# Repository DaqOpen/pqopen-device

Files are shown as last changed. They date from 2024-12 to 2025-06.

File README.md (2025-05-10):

# pqopen-device

**pqopen-device** is a cost-effective, open-source measurement device for monitoring voltage and current within electrical distribution panels. It includes power quality (PQ) functionalities compliant with **IEC 61000-4-30** and is designed for tech enthusiasts and educational institutions. It bases on the [daqopen-lib](https://github.com/DaqOpen/daqopen-lib) for  data acquisition and [pqopen-lib](https://github.com/DaqOpen/pqopen-lib) for the power quality processing part.

> [!WARNING] 
> The actual hardware design is not tested so far. Please wait until an official release.

## Key Features

- **Voltage Measurement**: Measure and analyze 3-phase mains voltage up to 330 VAC
- **Current Measurement**: Use clamps like SCT13-0000 for current measurement
- **Power Quality**: Analysis of RMS, Harmonics, Interharmonics, Flicker and more according to IEC 61000-4-30
- **Data Aggregation**: Use different storage intervals for logging selected parameters to CSV or MQTT
- **Cost-Effective**: Built using open-source hardware like the **Arduino Due** and **Raspberry Pi**.

## Target Audience

- **Tech Enthusiasts**: People interested in measurement technology and electrical energy supply.
- **Educational Institutions**: For training and research purposes.

## Hardware Overview

The device comprises:

- A custom **mainboard** with connectors, power supplies, and signal conditioning for voltage and current.
- **Arduino Due** for data acquisition (running with 55 kS/s per channel)
- **Raspberry Pi 3A+** as the edge device.
- A **standard DIN-rail enclosure** (9 module width).

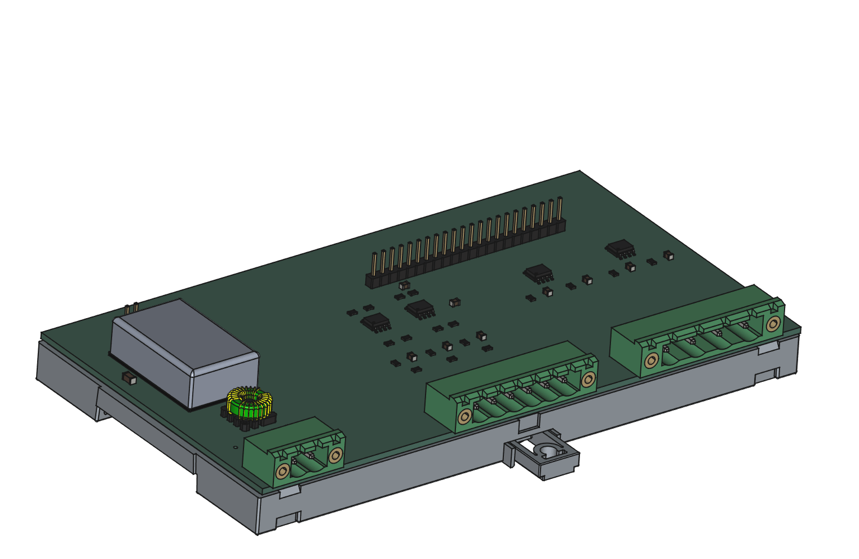
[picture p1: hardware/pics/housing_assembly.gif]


The main pcb is dual layer with components on both sides. It uses typically SMT components with down to size of 0805 to be soldered by hand.

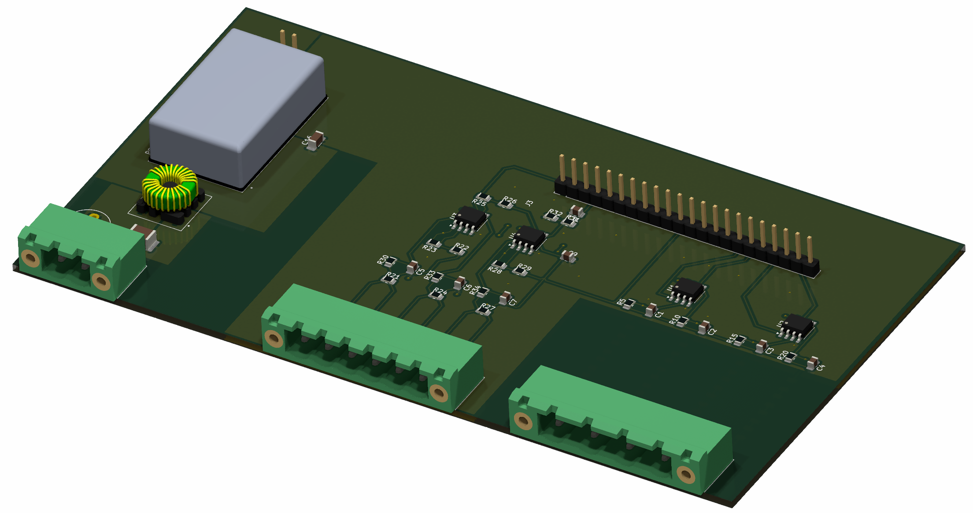
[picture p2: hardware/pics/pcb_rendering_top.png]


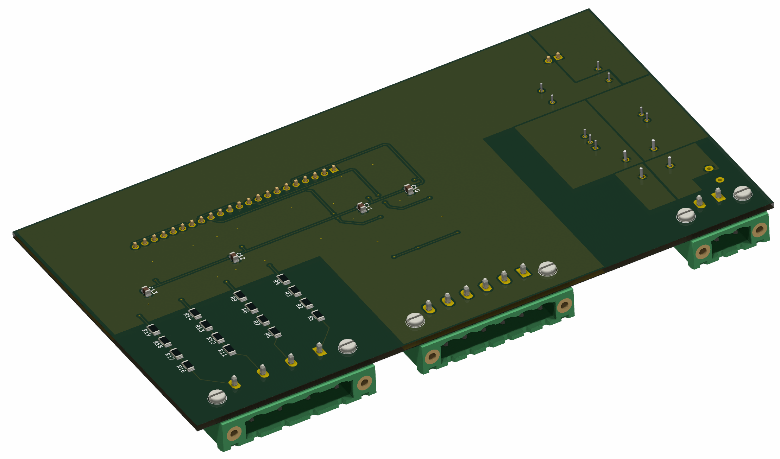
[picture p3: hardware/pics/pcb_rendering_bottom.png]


## Software Overview

The software is split into several components:

### Firmware for Arduino Due

Runs on the Arduino Due for ADC data acquisition (see https://github.com/DaqOpen/daqopen-lib)

Written in C++ for Arduino IDE

### Software for Raspberry Pi

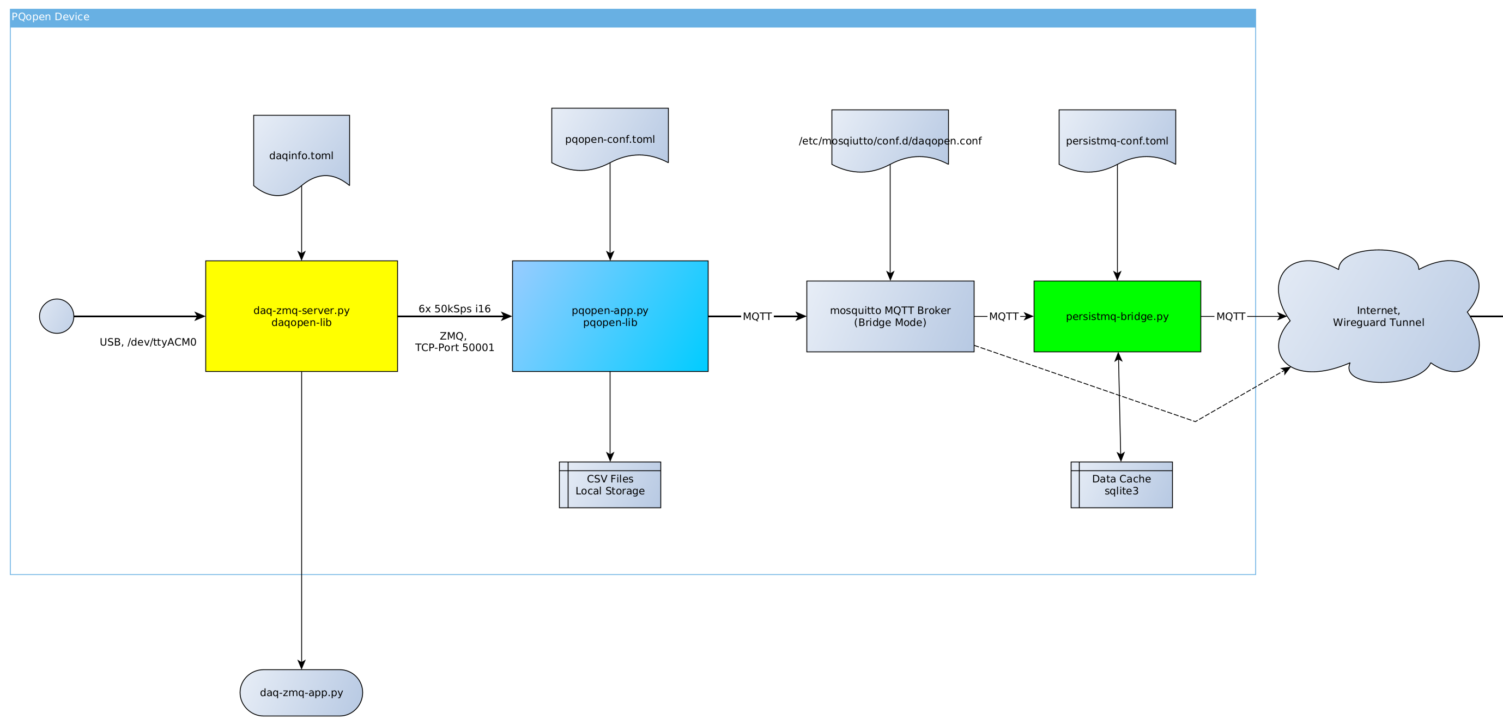
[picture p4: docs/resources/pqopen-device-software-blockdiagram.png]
PQopen Device Software


There are three main software components running on the Raspberry Pi edge device to fulfill the measurement needs:

#### daqopen-zmq-server.py

This is the data entry point for the further processing. It receives data form the Arduino Due, adds timestamps as well as channel properties and provides the data via a ZMQ PUB/SUB interface.

This service is time critical due to limited buffer on the Arduino Due and is therefore started with higher priority and realtime scheduler option.

#### pqopen.py

The pqopen app is the main processing application. It connects to the daqopen-zmq-server and receives the data, calculates power values and outputs it on the configured interfaces.

#### persistmq-bridge.py

When data loss is no option, the persistmq-bridge helps to cache data in case of connection loss and resending capability.

## Platform Compatibility

- **Core Library**: Runs on ARM64, AMD64, Linux, and Windows (Mac compatibility untested).
- **Main Application**: Designed specifically for the Raspberry Pi.

## Installation

An **initial setup guide** will be provided to assist with assembling the hardware and installing the software soon.

## Documentation

Documentation for the overarching project is available at [docs.daqopen.com](https://docs.daqopen.com). This documentation will be expanded to include specifics for pqopen-device.

## Contribution

Contributions are welcome, provided they align with the project's vision. Feel free to open issues, submit pull requests, or engage in discussions.

## License

This project is licensed under the **MIT License**.

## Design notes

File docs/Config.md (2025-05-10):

# Configuration

There are three main configuration files placed in /etc/pqopen/ directory.

| File | Configuration for |
| --- | --- |
| daqinfo.toml | daqopen-zmq-server<br />Information about the ACQ system, inputs and zmq server |
| pqopen-conf.toml | pqopen<br />Power system information and phases. Storing Endpoints |
| persistmq.conf | persistmq-bridge<br />Source and target of the MQTT messages; Cache-file |

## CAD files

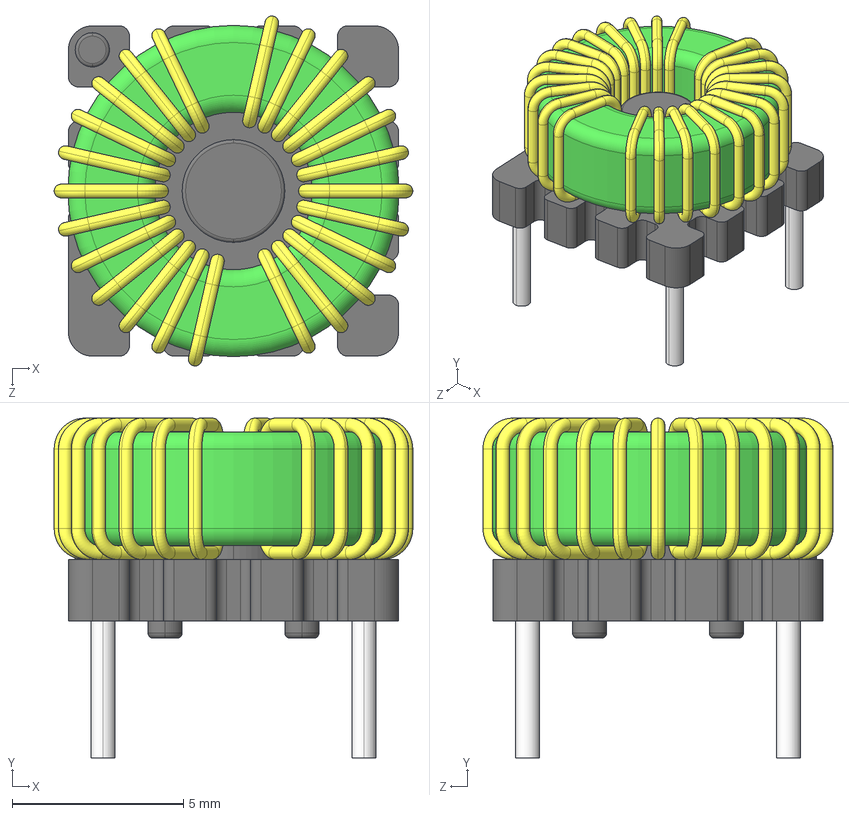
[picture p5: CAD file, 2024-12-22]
hardware/schematic-rail-mount/footprints/tck_050_3d_drawing.stp
10.5 x 9.93 x 10.2 mm

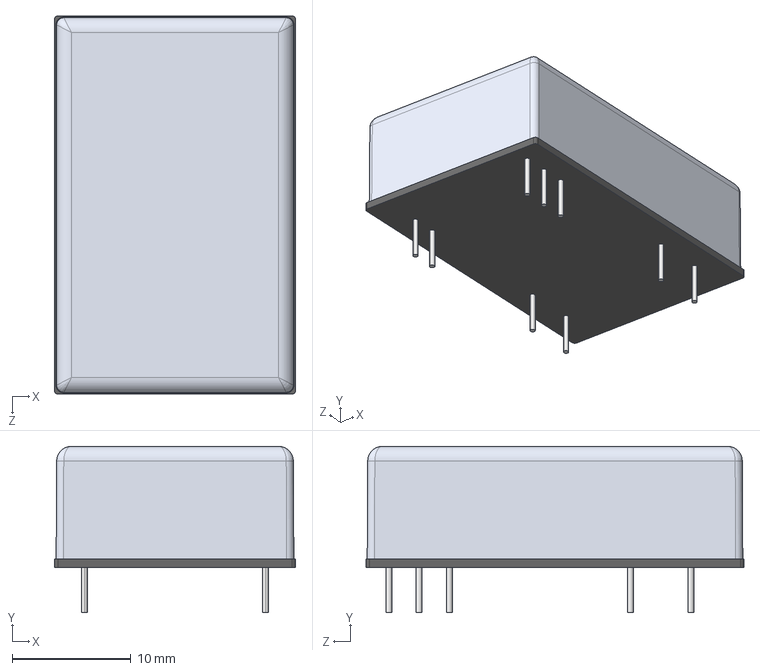
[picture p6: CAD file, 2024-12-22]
hardware/schematic-rail-mount/footprints/ten8wi_3d_drawing.stp
20.3 x 14.0 x 31.8 mm

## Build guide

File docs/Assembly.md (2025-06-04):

# Assembly of PQopen (Din-Rail)

This Section describes the assembly of the PQopen device. 

Components

| Item | Count | Info |
| --- | ----- | --- |
| pqopen-base-board | 1 | PQopen Base Board with pre-soldered top SMT parts |
| Arduino Due | 1 | Arduino Due is used as DAQ Board. Flashed with DueDaq Firmware<br />See [Arduino Setup](../../how-to/prepare-arduino-due.md) |
| Raspberry Pi 3A+  | 1 | Edge Computer + SD-Card (min. 8 GB) |
| 9TE Housing | 1 | e.g. Camdenboss CNMB/9/KIT |

Additional Parts for PCB Completion

| Item | Count | Info |
| --- | ----- | --- |
| TEN 8-2411WI | 1 | DC/DC Converter |
| TCK-050 | 1 | Filter Choke |
| C1812F475K5RACTU | 1 | DC Input Capacitor |
| Phoenix 1806245 | 1 | 4 Pos 7.62mm pitch Through Hole Header  |
| Phoenix 1858785 | 1 | 4 Pos 7.62mm pitch Plug 24-12 AWG Screw |
| Phoenix 1776540 | 1 | 6 Pos 5.08mm pitch Through Hole Header  |
| Phoenix 1778027 | 1 | 6 Pos 5.08mm pitch Plug 24-12 AWG Screw |
| Phoenix 1776508 | 1 | 2 Pos 5.08mm pitch Through Hole Header  |
| Phoenix 1777989 | 1 | 2 Pos 5.08mm pitch Plug 24-12 AWG Screw |
| ROHM KTR18EZPF4703 | 16 | 470 kOhm Resistors for input divider |

## Step 1: Completion of PCB

This chapter shows the completion of the PCB of Revision 1.

### Power Supply

At first, we start with the power supply part. For this step, we need the following parts:

| | Count | Info |
| --- | ----- | --- |
| TEN 8-2411WI | 1 | DC/DC Converter |
| TCK-050 | 1 | Filter Choke |
| C1812F475K5RACTU | 1 | DC Input Capacitor |
| T2A | 1 | Input fuse 2A |

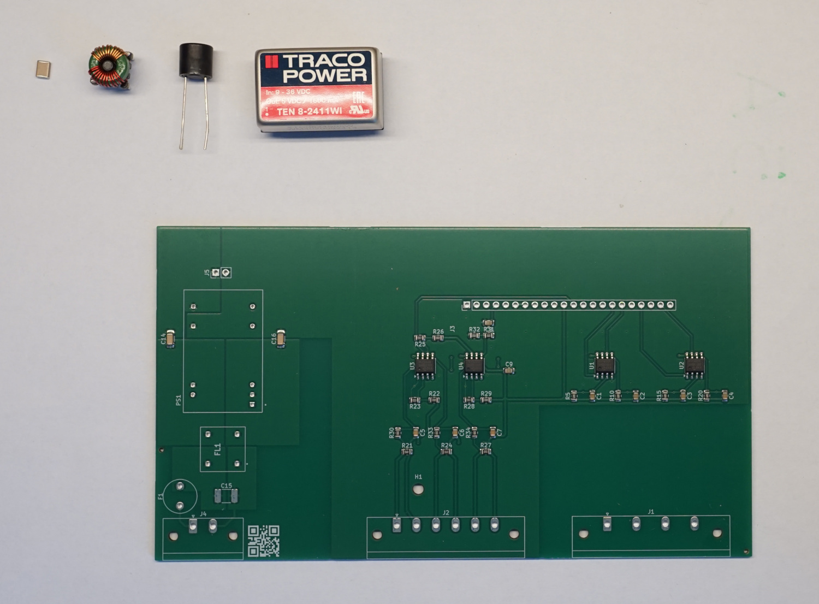
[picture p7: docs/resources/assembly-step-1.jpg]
Step1


Start with the smallest part, the capacitor.

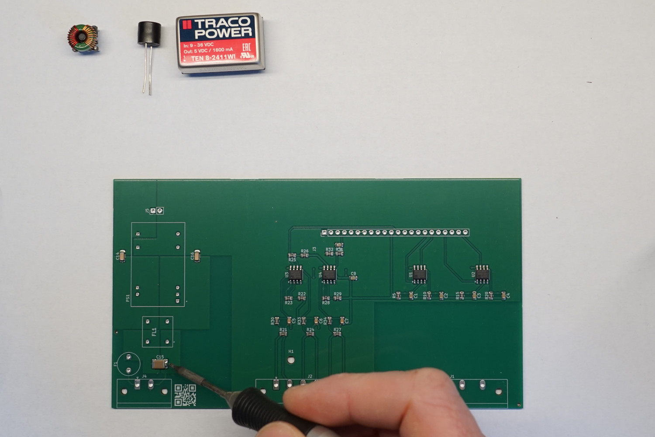
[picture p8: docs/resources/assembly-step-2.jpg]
Step1-A


And work towards the DC/DC converter:

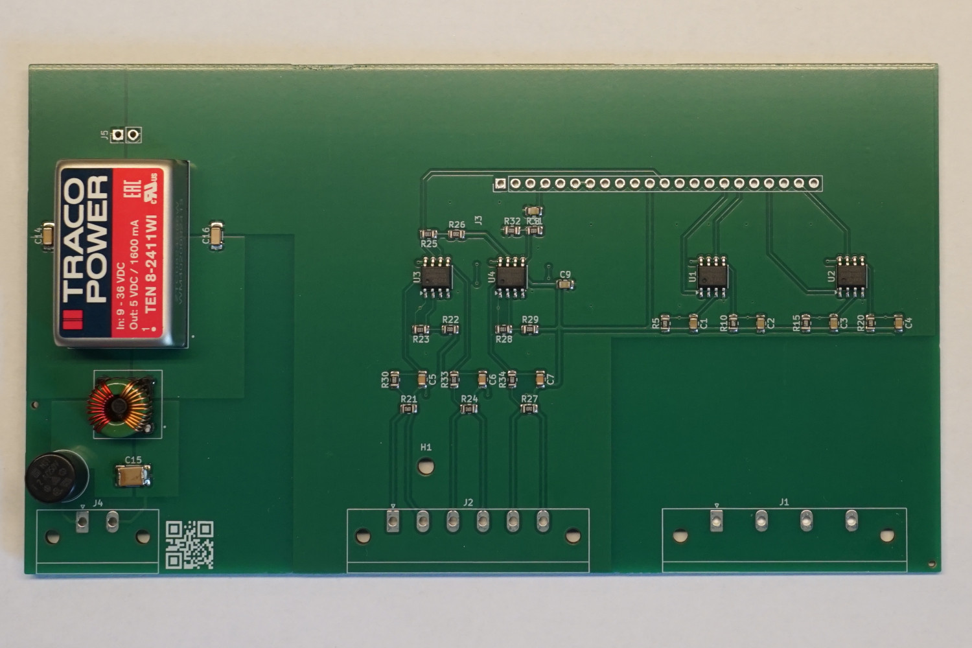
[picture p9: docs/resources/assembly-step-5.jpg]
Step1-B


### Backside Capacitors

C10-C13: 100nF 0805

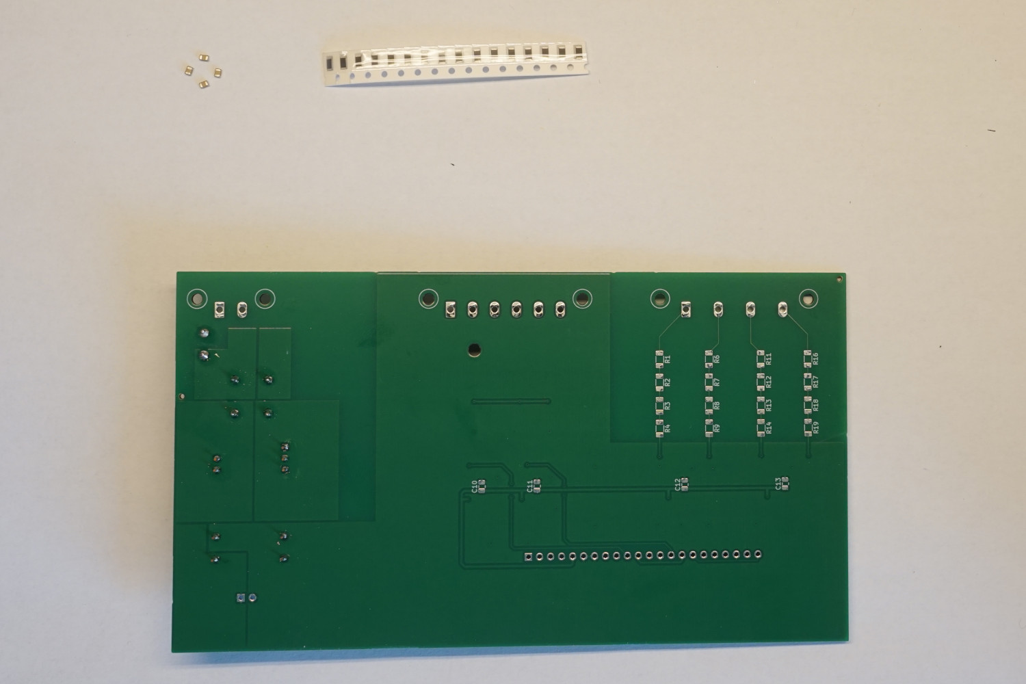
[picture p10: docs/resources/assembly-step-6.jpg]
Step3-A


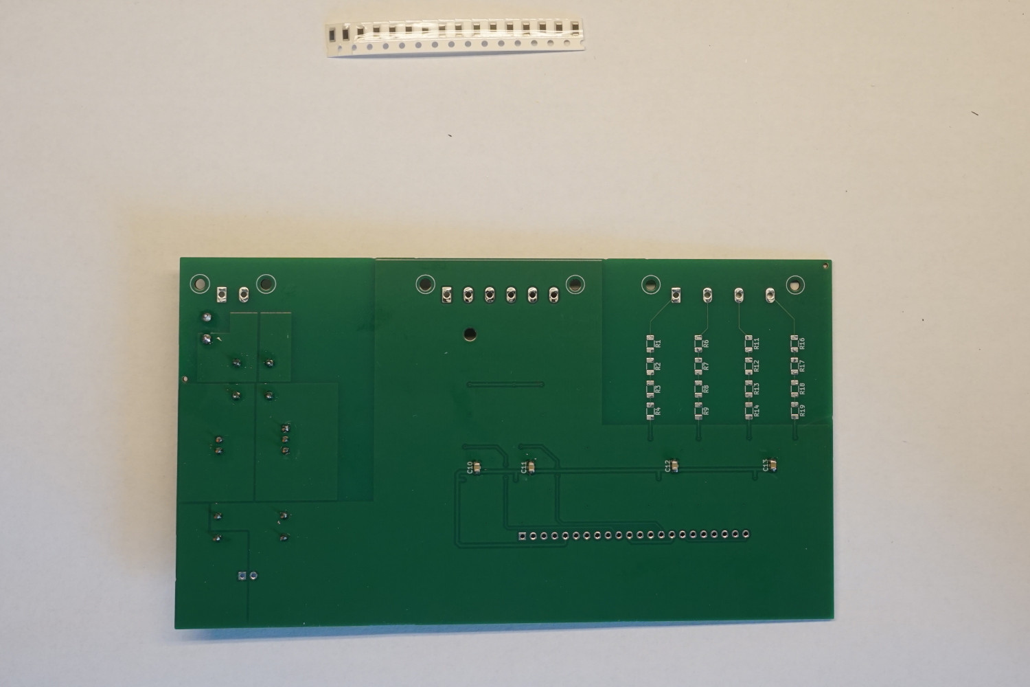
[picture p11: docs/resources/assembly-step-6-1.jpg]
Step3-B


### Input voltage divider

The resistive voltage divider is used to reduce the power grid voltage to ADC levels. It consists of each 4 resistors. 

#### Resistor selection (optional)

To improve accuracy across all 3 input channels, the resistors should be equal value. One option to select the right combination of resistors of each string, is, to sort the resistors according to actual measured value. My way of doing this is, checking each resistor and placing it on a scale, which I draw on paper.

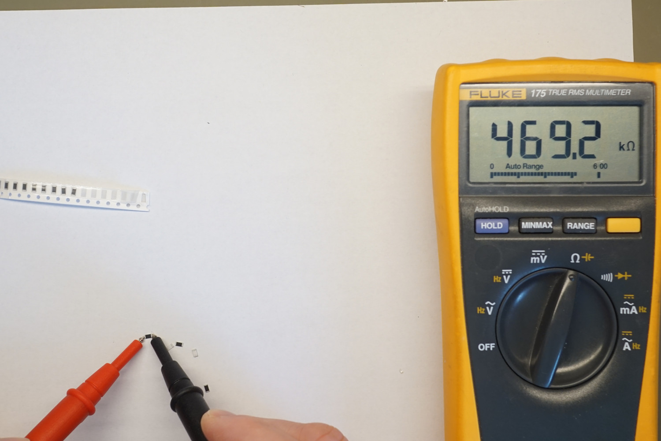
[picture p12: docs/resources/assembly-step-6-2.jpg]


After sorting all resistors, the placement should look something like this:

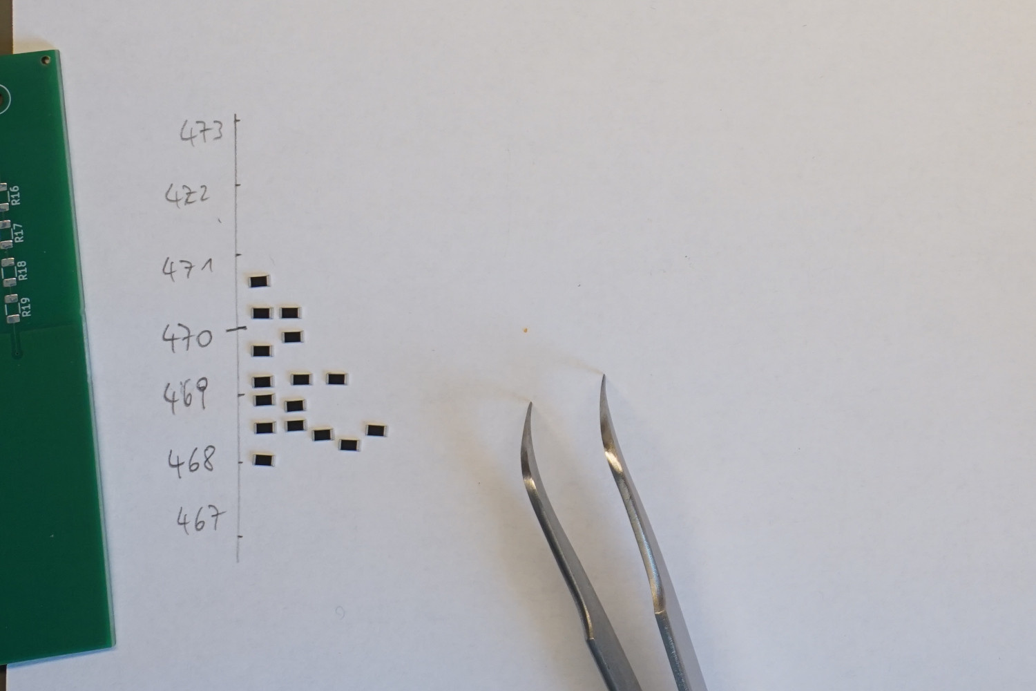
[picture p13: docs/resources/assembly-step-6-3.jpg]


Now use the resistors alternating top and bottom. This should give you a good mix of values to reach almost same series value.

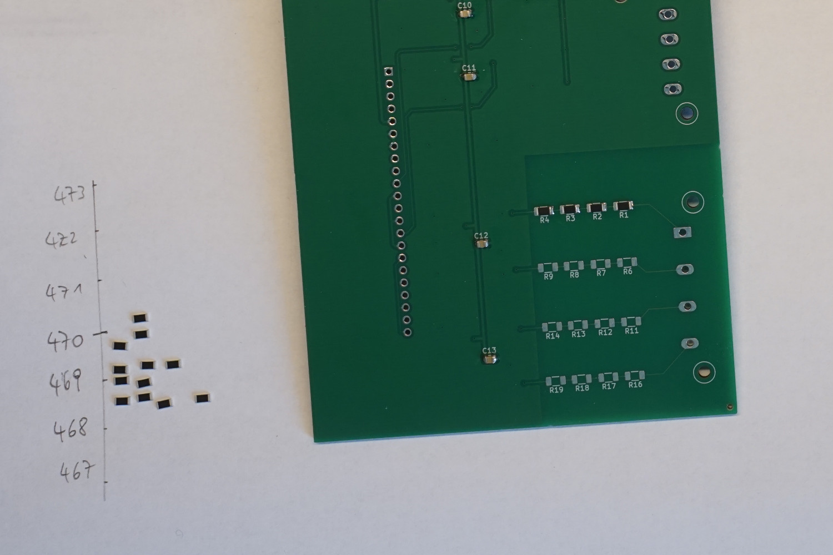
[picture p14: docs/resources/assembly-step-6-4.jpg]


Here I used the two most top and tow of most bottom resistors and placed them on the first string.

#### Finishing voltage divider

Place all 16 resistors to finish the voltage input divider.

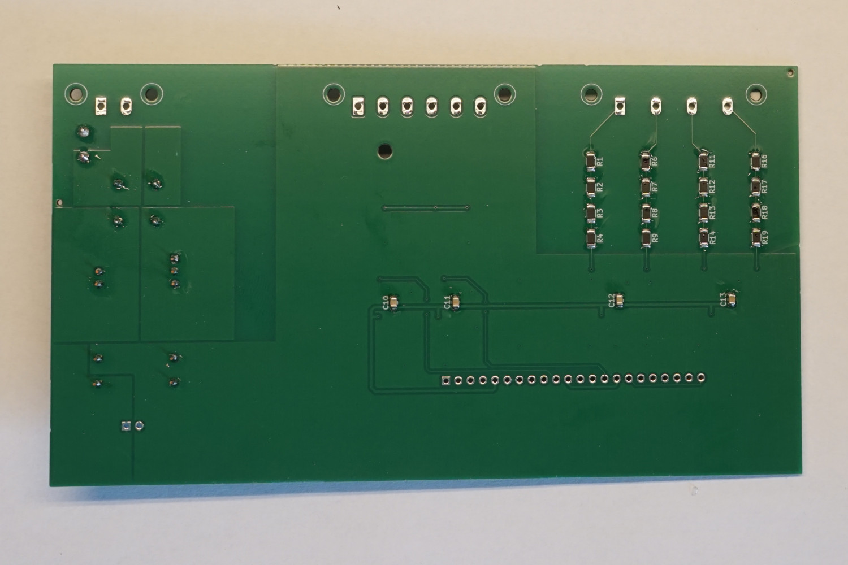
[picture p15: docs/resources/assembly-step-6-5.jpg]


### Pinheader for Arduino

Next, we'll place the pinheader for the Arduino Due. You need a standard 2.54 RM Pinheader with 22 pins. Remove the pins from position 9 and 18 to fit with the Arduino socket.

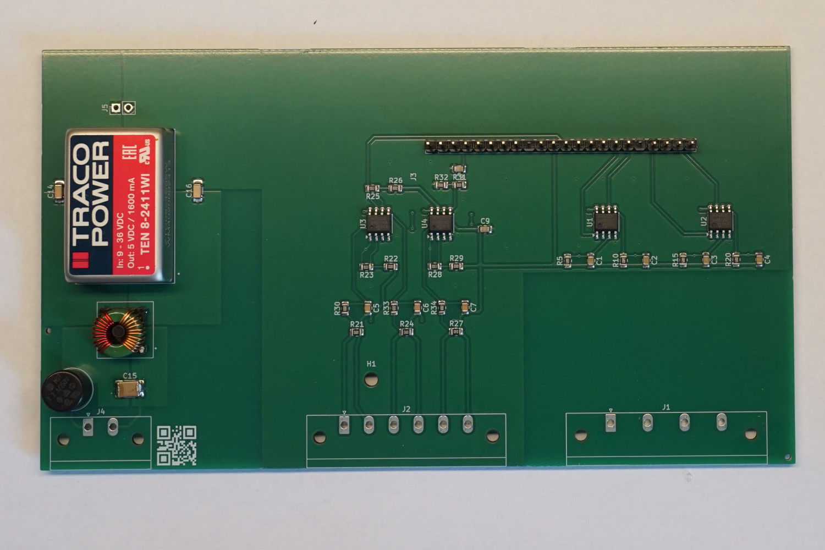
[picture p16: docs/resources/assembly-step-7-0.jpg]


### Input connectors

To finish the PCB assembly, solder the input connectors for power supply, current sensor and voltage input.

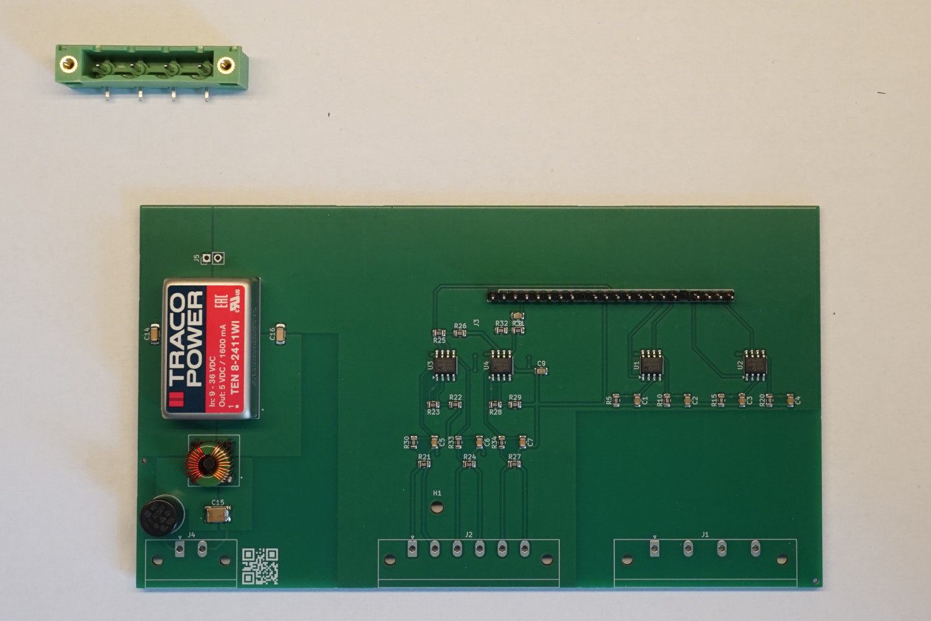
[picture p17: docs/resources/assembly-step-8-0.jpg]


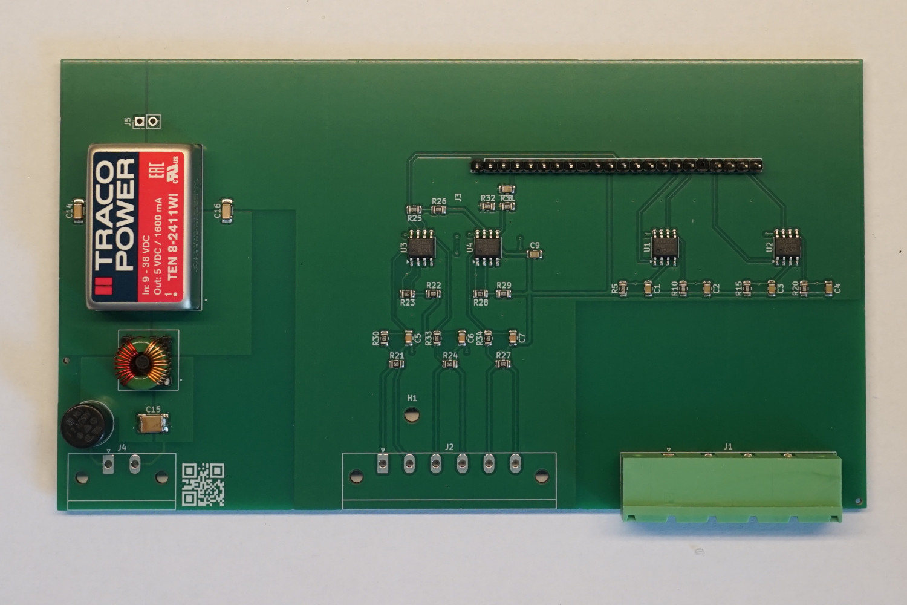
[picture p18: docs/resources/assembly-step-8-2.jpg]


Great, you finished the PCB and can move on with attaching the Arduino.

## Step 2: Attach Arduino and RPi

The Arduino is stacked on the PCB and fixated with a nylon screw. On top of the Arduino, the Raspberry Pi is mounted.

You need 1 placeholder with internal thread, 2 two-sided ones, 3 screws and one bolt.

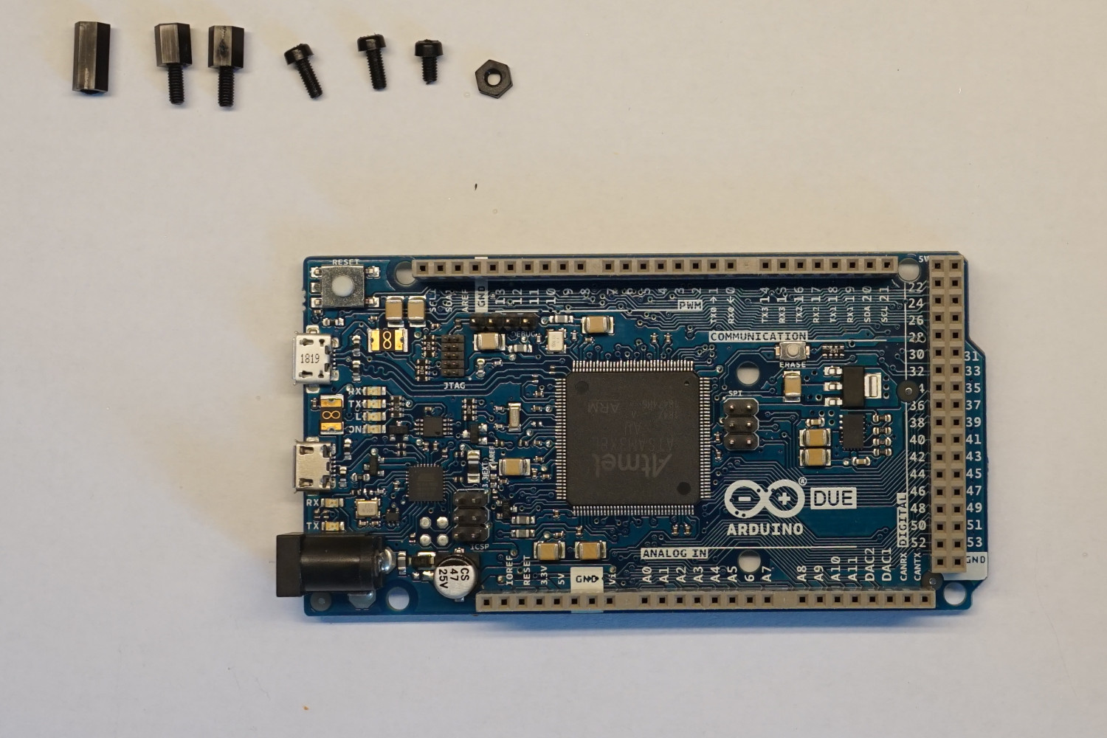
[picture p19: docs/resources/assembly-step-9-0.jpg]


Use the placeholder as well as the two screws with internal thread and the bolt and attach them to the Arduino.

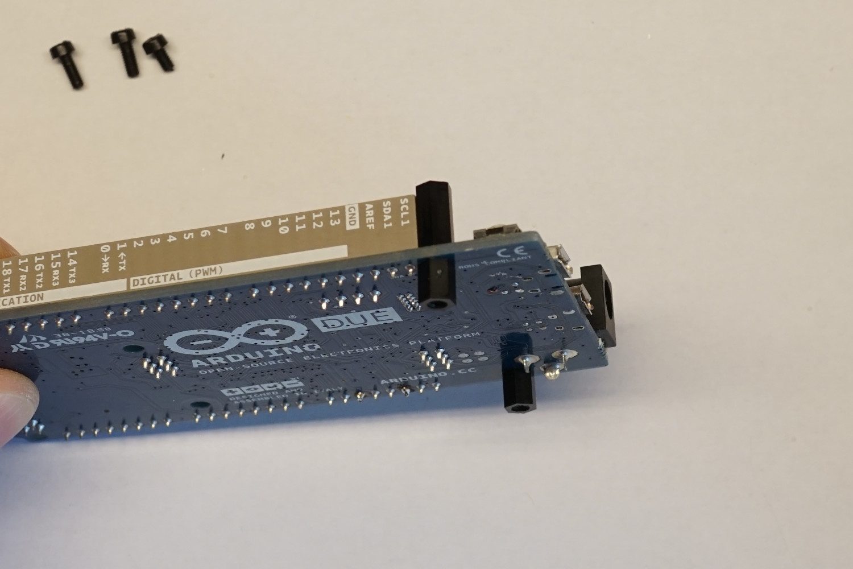
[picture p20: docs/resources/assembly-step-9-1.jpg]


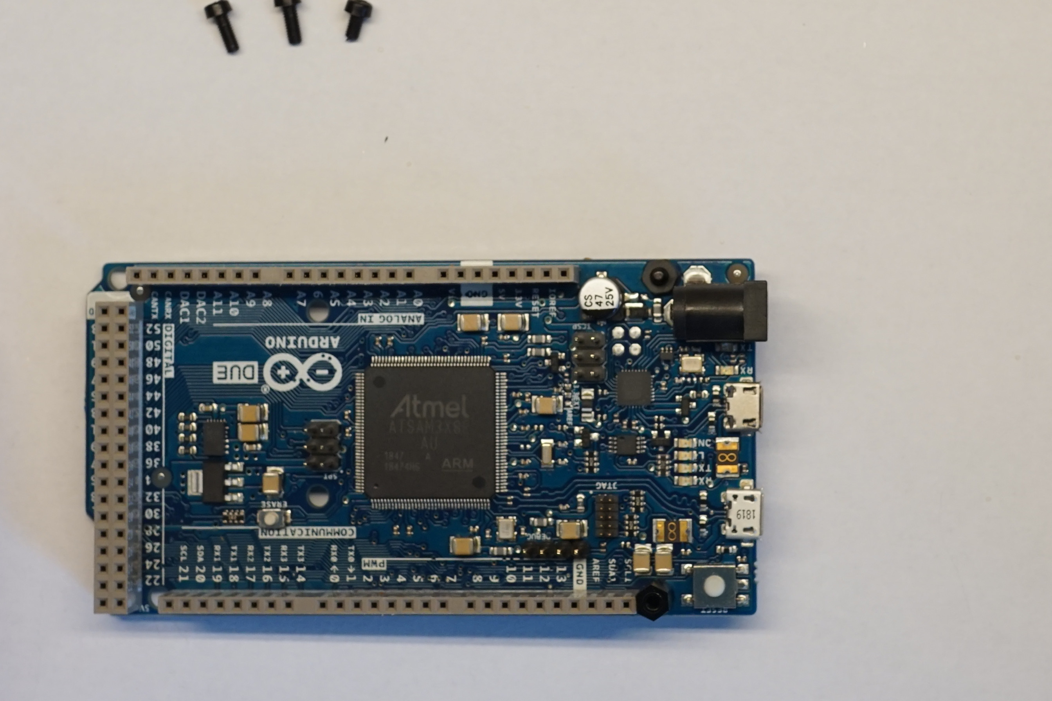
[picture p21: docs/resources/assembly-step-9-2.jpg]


#### Prepare Raspberry Pi

Use an additional pair of screws and bolts to safely distant the Raspberry from the Arduino

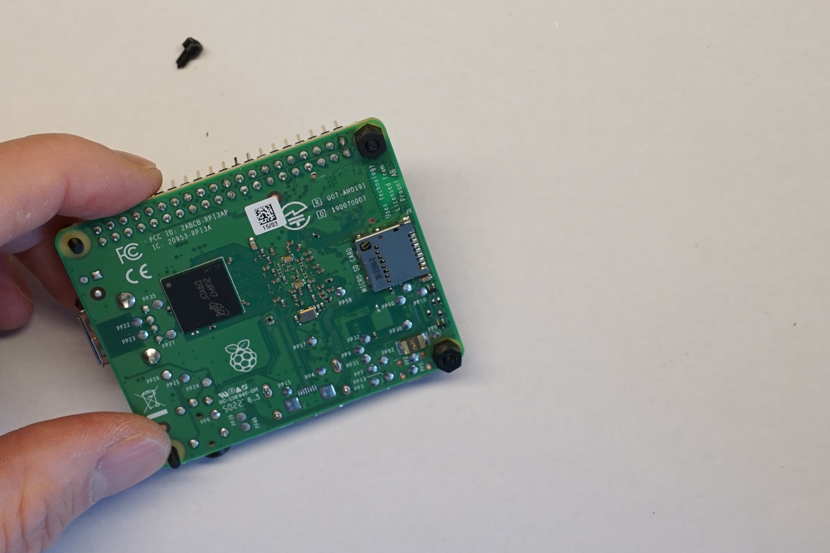
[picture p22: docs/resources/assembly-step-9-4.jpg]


Place the Raspberry on the bottom side of the Arduino (back-to-back) and fix them together the two remaining screws. Before fastening the screws, be sure, both of the screws are in the thread (it is a bit tricky, because it is not 100% in alignment). The flexibility of the nylon components helps to get it done.

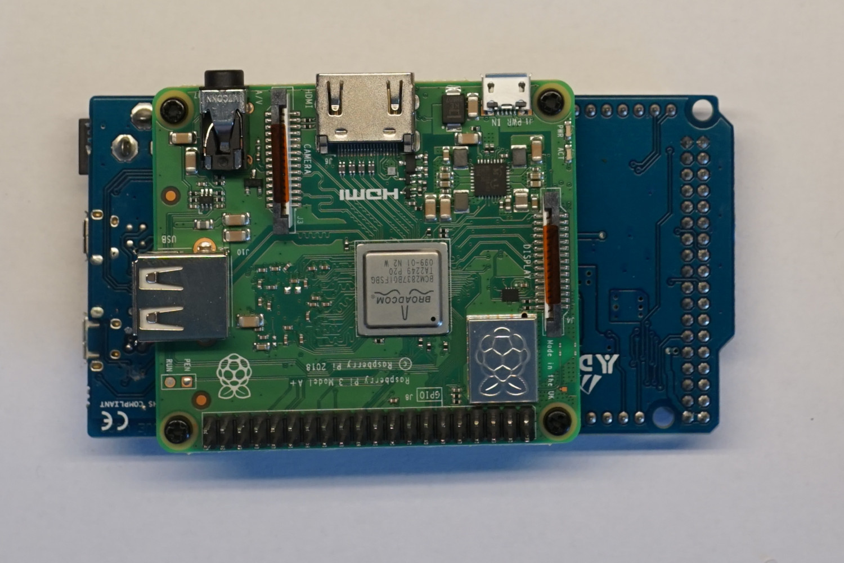
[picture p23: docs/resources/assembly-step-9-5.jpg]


### Marriage of PCB and Arduino

One of the last step is now, to connect the Arduino/RPi to the PCB and fix it with another nylon screw.

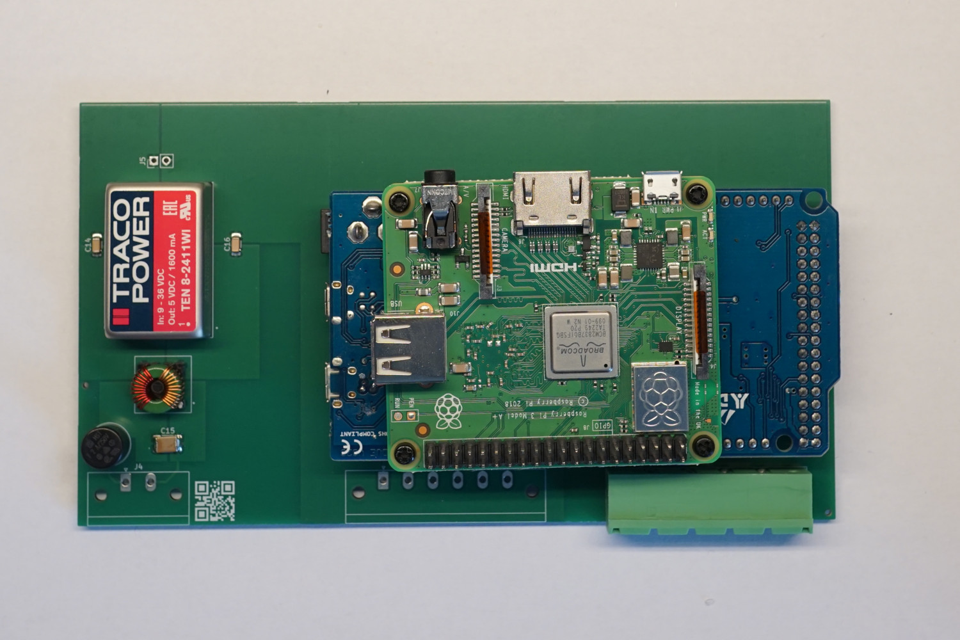
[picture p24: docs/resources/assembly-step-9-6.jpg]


Note the screw hole in the top-middle of the PCB backside:

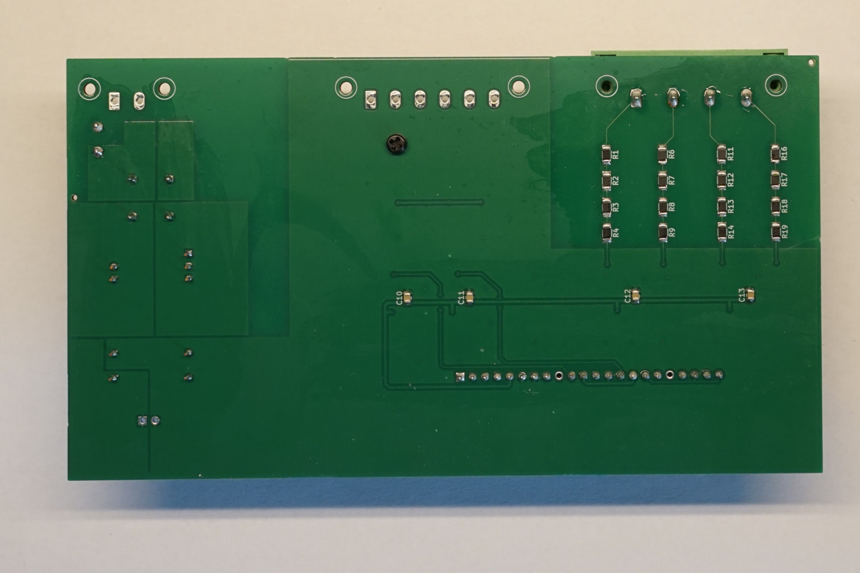
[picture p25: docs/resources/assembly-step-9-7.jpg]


The last step is now to wire the USB-Cable and Power Supply (power connection is missing on this picture)

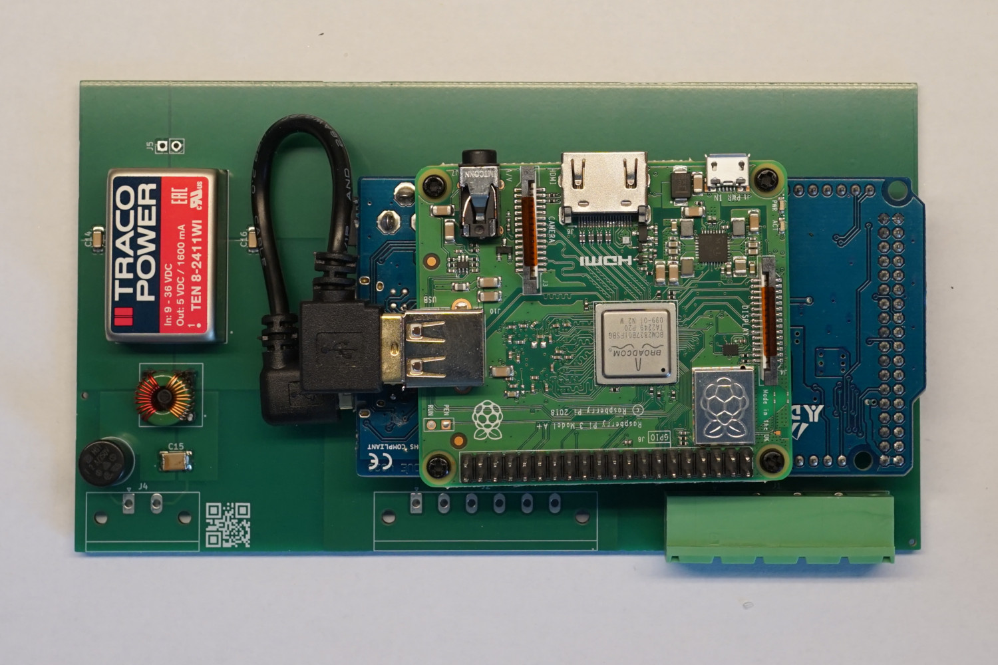
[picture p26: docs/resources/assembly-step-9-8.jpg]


## Step 3: Electrical Check

To check the components and right assembly, we can do a quick-check if everything is working.

1. Temporary disconnect the USB cable and connect the Arduino directly to the PC
2. ... 

## Step 4: Attach Housing

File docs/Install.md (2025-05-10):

# Installation and Software Setup

This document describes the software setup and installation for the embedded Raspberry Pi. 

## Step 1: Create RPi Image

Prepare a SD-Card with an Raspbian OS Lite Image. Follow instructions here: https://www.raspberrypi.com/software/

Use the rpi-imager and set at least the following parameters:

- Your WiFi AP Name and Key
- Username: daqopen with your password
- Hostname: eg. pqopen-1

I recommend setting an ssh-key for secure access without password.

Attach the pre-configured SD-Card to your Raspberry Pi and Power Up.

Connect via SSH to the Raspberry Pi

```bash
ssh daqopen@pqopen-1
```

## Step 2: Install essential packages

To clone the git-repository, git must be installed. Before that, we will do a system update.

```bash
sudo apt update
sudo apt upgrade
sudo apt install git vim
```

## Step 3: Clone Repo and run install script

Now we will clone the repository and run the install script, which takes care of creating a virtual python environment, creating directories and copying necessary files.

Make sure, that the user daqopen is in sudoers list!

```bash
git clone https://github.com/DaqOpen/pqopen-device.git
cd pqopen-device
chmod +x install.sh
./install.sh
```

## Step 3.1 (optional) Configure Comitup

For headless WiFi setup, the Comitup service from https://github.com/davesteele/comitup  is used.

Modify the comitup config file, to customize the settings (e.g. set an AP password)

```bash
vi /etc/comitup.conf
```

## Step 4: Reboot

When the install script finished, please reboot the device.

```bash
sudo reboot
```

## Step 5: System Check

Now it is time to check, if everything is working as expected

### Check Arduino Connection

Make sure, that the Arduino Due with DueDaq Firmware is connected via USB (Native USB) to the Raspberry Pi.

Check if Arduino Due is recognized by the system. Run the following command:

```bash
lsusb
```

The output should show at least the following lines:

```
Bus 001 Device 002: ID 2341:003e Arduino SA Due
Bus 001 Device 001: ID 1d6b:0002 Linux Foundation 2.0 root hub
```

Important is the listing of the Arduino SA Due.

### Check Service Status

Now we can check the status of the different services

#### daqopen-zmq-server

This service's task is to read the acquired data from the Arduino Due board, add scaling and timing information and publish the data via a ZMQ socket.

```bash
sudo systemctl status daqopen-zmq-server
```

The output should show something like this:

```
● daqopen-zmq-server.service - daqopen-zmq-server Service
     Loaded: loaded (/etc/systemd/system/daqopen-zmq-server.service; enabled; preset: enabled)
     Active: active (running) since Fri 2025-05-09 08:04:17 CEST; 1 day 3h ago
   Main PID: 3031 (python)
      Tasks: 3 (limit: 179)
        CPU: 1h 39min 32.958s
     CGroup: /system.slice/daqopen-zmq-server.service
             └─3031 /opt/pqopen/.venv/bin/python daqopen-zmq-server.py --config /etc/pqopen/daqinfo.toml
```

Important is the Active state *active (running)*

#### pqopen

This is the main service for calculating the power values and creating the output.

```
sudo systemctl status pqopen
```

The output should show something like this:

```
● pqopen.service - pqopen Service
     Loaded: loaded (/etc/systemd/system/pqopen.service; enabled; preset: enabled)
     Active: active (running) since Sat 2025-05-10 09:33:47 CEST; 2h 16min ago
   Main PID: 5641 (python)
      Tasks: 4 (limit: 179)
        CPU: 1h 13min 23.252s
     CGroup: /system.slice/pqopen.service
             └─5641 /opt/pqopen/.venv/bin/python pqopen-app.py --config /etc/pqopen/pqopen-config.toml

```

Important is the Active state *active (running)*

#### persistmq-bridge

The third service is used to bridge MQTT messages from the local broker to a remote broker and taking care of message caching in case of connection errors.

This is optional and can be replaced by a bridge config of the mosquitto broker or directly publishing to the target broker.

```bash
sudo systemctl status persistmq-bridge
```

## Finished installation

Now you finished the installation process and first checks of the system. Now, we can take care of appropriate configuration and adjustment.

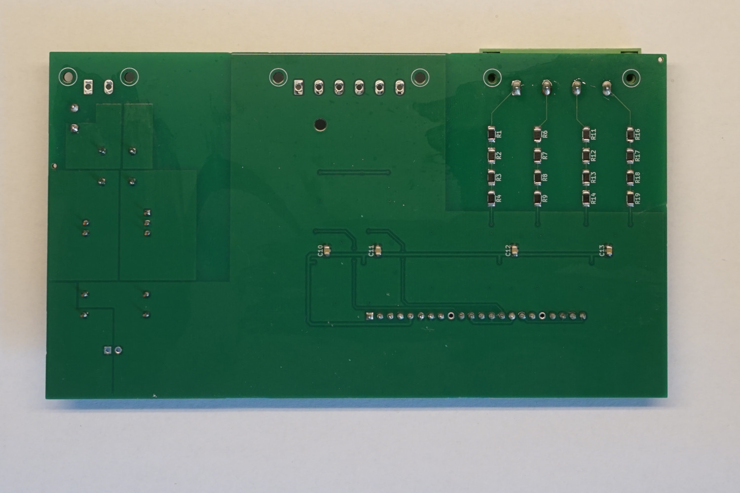
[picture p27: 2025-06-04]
docs/resources/assembly-step-8-1.jpg

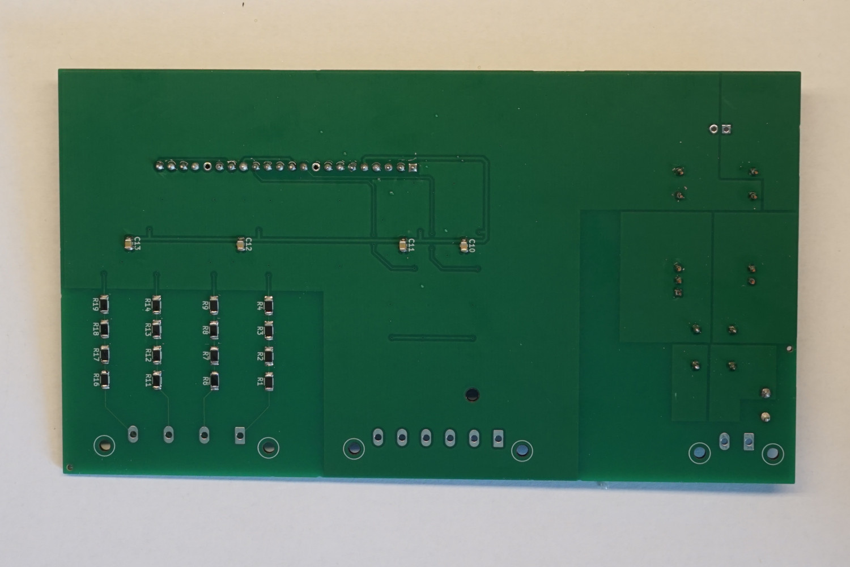
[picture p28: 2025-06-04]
docs/resources/assembly-step-7-1.jpg

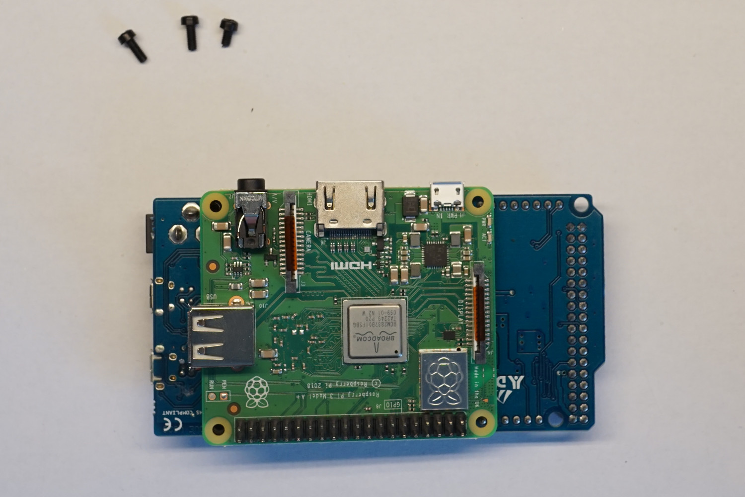
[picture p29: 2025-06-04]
docs/resources/assembly-step-9-3.jpg

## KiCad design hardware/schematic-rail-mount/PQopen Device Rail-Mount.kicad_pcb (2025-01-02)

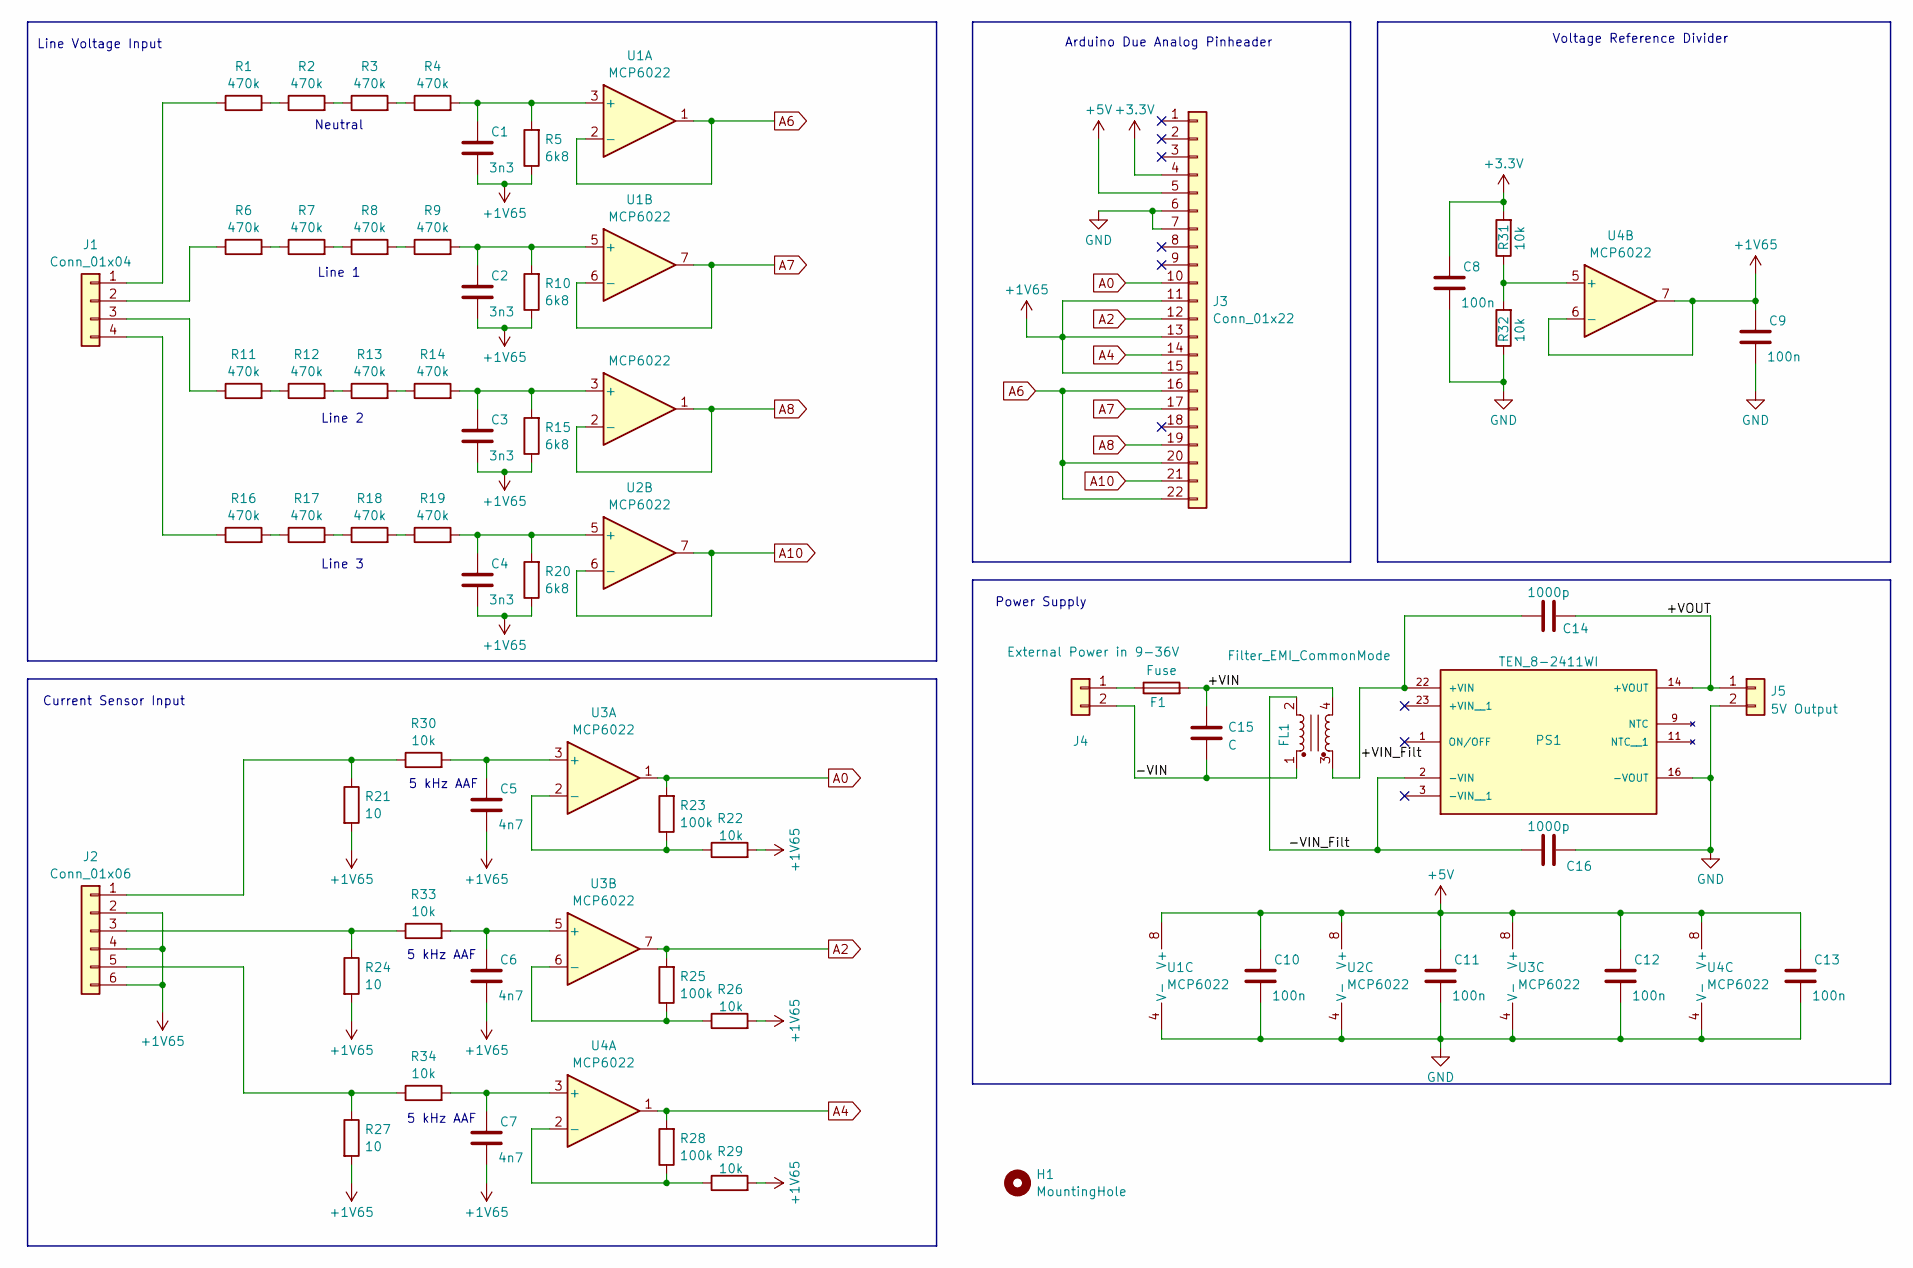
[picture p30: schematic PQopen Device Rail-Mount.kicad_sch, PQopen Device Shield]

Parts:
C1, C2, C3, C4: 3n3; C_0805_2012Metric
C5, C6, C7: 4n7; C_0805_2012Metric
C8, C9, C10, C11, C12, C13: 100n; C_0805_2012Metric
C14, C16: 1000p; C_1206_3216Metric_Pad1.33x1.80mm_HandSolder; Part Number 1206GC102KAT1A
C15: C; C_1812_4532Metric_Pad1.57x3.40mm_HandSolder; Part Number C1812F475K5RACTU
F1: Fuse; Fuse_Littelfuse_372_D8.50mm
FL1: Filter_EMI_CommonMode; TCK050
H1: MountingHole; MountingHole_2.7mm_M2.5_ISO14580
J1: Conn_01x04; PhoenixContact_GMSTB_2,5_4-GF-7,62_1x04_P7.62mm_Horizontal_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
J2: Conn_01x06; PhoenixContact_MSTB_2,5_6-GF-5,08_1x06_P5.08mm_Horizontal_T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
J3: Conn_01x22; PinHeader_1x22_P2.54mm_Vertical
J4: External Power in 9-36V; PhoenixContact_MSTB_2,5_2-GF-5,08_1x02_P5.08mm_Horizontal_T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
J5: 5V Output; PinHeader_1x02_P2.54mm_Vertical
PS1: TEN_8-2411WI; CONV_TEN_8-2411WI; PARTREV September 29, 2020
R1, R2, R3, R4, R6, R7, R8, R9, R11, R12, R13, R14, R16, R17, R19: 470k; R_1206_3216Metric
R5, R10, R15, R20: 6k8; R_0805_2012Metric
R18: 470k; R_1206_3216Metric; mpn KTR18EZPF4703
R21, R24, R27: 10; R_0805_2012Metric
R22, R26, R29, R30, R31, R32, R33, R34: 10k; R_0805_2012Metric
R23, R25, R28: 100k; R_0805_2012Metric
U1, U2, U3, U4: MCP6022; SOIC-8_3.9x4.9mm_P1.27mm

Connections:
+1V65: C1.2, C2.2, C3.2, C4.2, C5.2, C6.2, C7.2, C9.1, J2.2, J2.4, J2.6, J3.11, J3.13, J3.15, R5.1, R10.1, R15.1, R20.1, R21.2, R22.2, R24.2, R26.2, R27.2, R29.2, U4.6 (-), U4.7
+3.3V: C8.1, J3.4, R31.2
+5V: C10.1, C11.1, C12.1, C13.1, J3.5, U1.8 (V+), U2.8 (V+), U3.8 (V+), U4.8 (V+)
/+VIN: C15.1, F1.2, FL1.4
/+VIN_Filt: C14.1, FL1.3, PS1.22 (+VIN)
/+VOUT: C14.2, J5.1, PS1.14 (+VOUT)
/-VIN: C15.2, FL1.1, J4.2
/-VIN_Filt: C16.1, FL1.2, PS1.2 (-VIN)
A0: J3.10, R23.2, U3.1
A2: J3.12, R25.2, U3.7
A4: J3.14, R28.2, U4.1
A6: J3.16, J3.20, J3.22, U1.1, U1.2 (-)
A7: J3.17, U1.6 (-), U1.7
A8: J3.19, U2.1, U2.2 (-)
A10: J3.21, U2.6 (-), U2.7
GND: C8.2, C9.2, C10.2, C11.2, C12.2, C13.2, C16.2, J3.6, J3.7, J5.2, PS1.16 (-VOUT), R32.1, U1.4 (V-), U2.4 (V-), U3.4 (V-), U4.4 (V-)
unnamed: J1.1, R1.1
unnamed: J1.2, R6.1
unnamed: J1.3, R11.1
unnamed: J1.4, R16.1
unnamed: J2.1, R21.1, R30.1
unnamed: J2.3, R24.1, R33.1
unnamed: J2.5, R27.1, R34.1
unnamed: F1.1, J4.1
unnamed: R1.2, R2.1
unnamed: R2.2, R3.1
unnamed: R3.2, R4.1
unnamed: R6.2, R7.1
unnamed: R7.2, R8.1
unnamed: R8.2, R9.1
unnamed: R11.2, R12.1
unnamed: R12.2, R13.1
unnamed: R13.2, R14.1
unnamed: R16.2, R17.1
unnamed: R17.2, R18.1
unnamed: R18.2, R19.1
unnamed: C1.1, R4.2, R5.2, U1.3 (+)
unnamed: C2.1, R9.2, R10.2, U1.5 (+)
unnamed: C3.1, R14.2, R15.2, U2.3 (+)
unnamed: C4.1, R19.2, R20.2, U2.5 (+)
unnamed: C5.1, R30.2, U3.3 (+)
unnamed: R22.1, R23.1, U3.2 (-)
unnamed: C6.1, R33.2, U3.5 (+)
unnamed: R25.1, R26.1, U3.6 (-)
unnamed: C7.1, R34.2, U4.3 (+)
unnamed: R28.1, R29.1, U4.2 (-)
unnamed: R31.1, R32.2, U4.5 (+)

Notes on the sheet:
Neutral
5 kHz AAF
Line 3
Line Voltage Input
Line 1
Voltage Reference Divider
Current Sensor Input
Arduino Due Analog Pinheader
Power Supply
Line 2

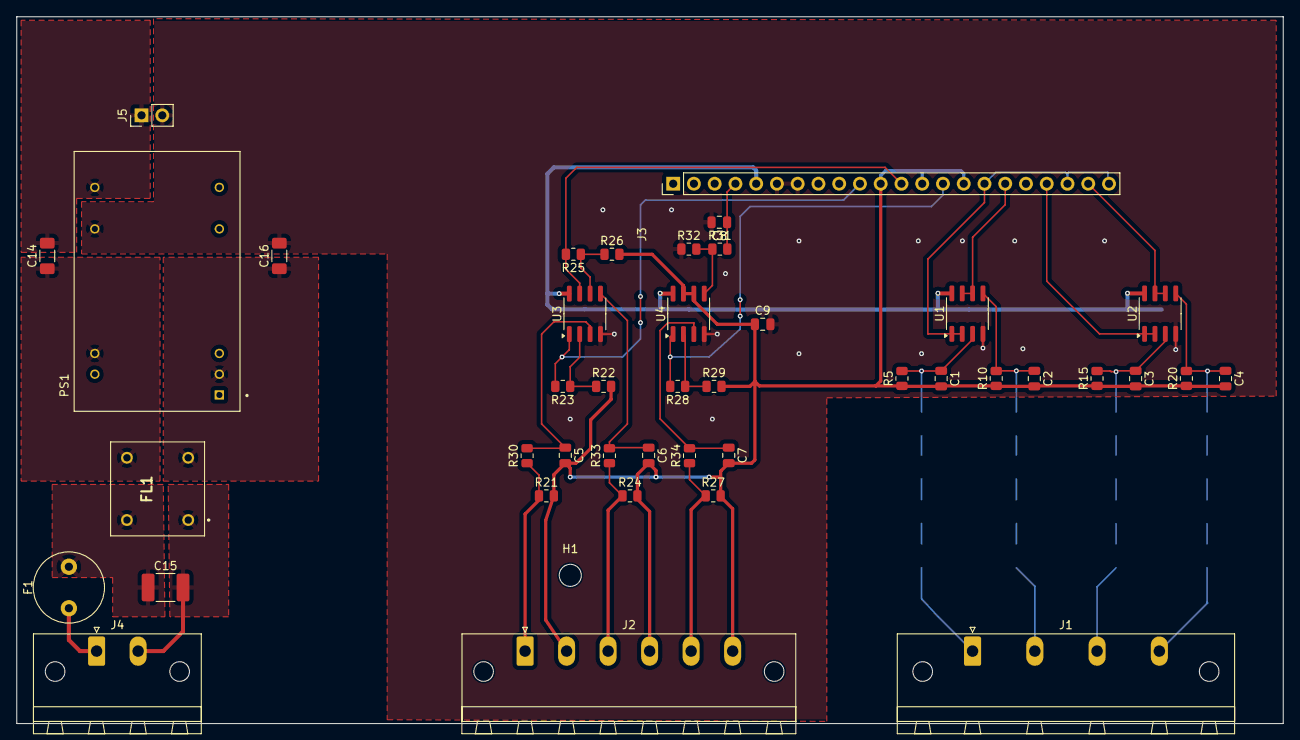
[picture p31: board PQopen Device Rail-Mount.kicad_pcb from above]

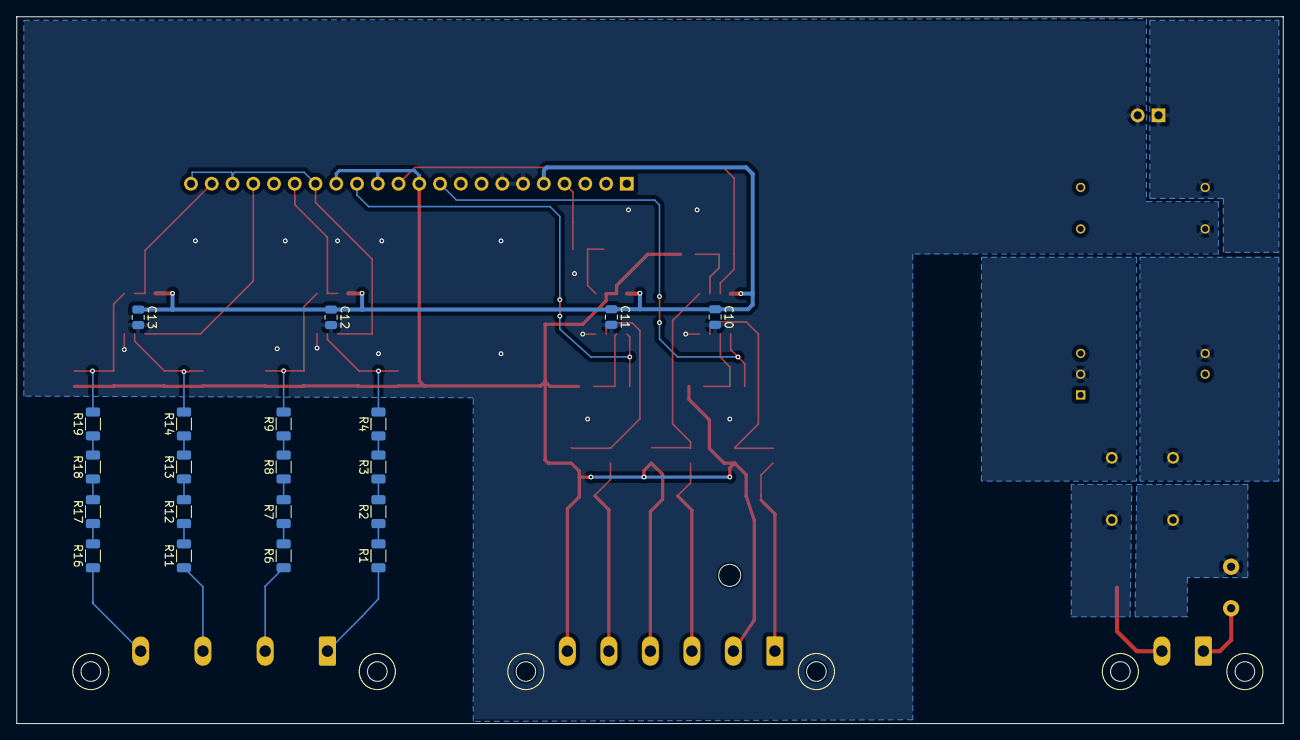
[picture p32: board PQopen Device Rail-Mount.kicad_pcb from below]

Board: 2 copper layers, 155.0 x 86.5 mm, 63 parts (20 on the bottom side), 47 nets.

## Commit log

2024-12-22 hardware: initial commit of schematic and draft of pcb
    [PQopen Device Rail-Mount.kicad_pcb, PQopen Device Rail-Mount.kicad_sch, tck_050_3d_drawing.stp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]
2025-01-02 hardware: minor improvements
    [PQopen Device Rail-Mount.kicad_pcb, PQopen Device Rail-Mount.kicad_sch]
2025-01-20 pqopen-app: reduced num-threads to 1; increase acq sample buffer to 200_000
2025-02-07 fixed problem reading device_id; tie daqopen process to CPU in unit file
2025-06-04 docs: added assembly instructions
2025-06-20 status-monitor: try to blink with about 1Hz
2025-06-20 status-monitor: also enable blinking on yellow led
2025-08-06 daq-zmq-server: correction of timestamp with board property adc_delay_seconds
2025-12-23 pqopen-app: added support for storing measurement config to storage endpoints
    [PQopen Device Rail-Mount.kicad_pcb, PQopen Device Rail-Mount.kicad_sch, tck_050_3d_drawing.stp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]
2026-02-01 daq-zmq-server: don't quit in case of packet jitter, just write warning.
